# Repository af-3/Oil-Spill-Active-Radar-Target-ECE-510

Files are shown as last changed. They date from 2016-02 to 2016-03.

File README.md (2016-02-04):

# Oil-Spill-Active-Radar-Target-ECE-510
Cooperating radar target design for Portland State University ECE 510 winter 2016 Class<br>
[Radar Equations google Dock](https://docs.google.com/spreadsheets/d/1SBJ6qjm3yuyV2hIqerSS4fywFo_I5tQoiRfdYXWfvTU/pubhtml)

##Requirements
 * Must
   * Have a detection range of 10 meters
   * Be enviromentaly friendy specifically marine friendy
   * Build 8 working targets, but support at least 64 targets
   * Function correctly for at least 48 hours
   * Software must detect at least 64 targets
 * Should
   * Be no bigger then 3 X 3 X 2 inches
   * Have a detection range of 100 meters 
 * Could
   * Have smart tracking capability

##Additional Notes
 * Radar transmitter output power -6.02 dBm (.25 mW)
 * Radar operating frequincy is 2.304080 GHz
 * Antenna beam width on the vertical axis is about 68 digrees
 * Antenna beam width on the horizontal axis is about 52 digrees
 * Measured Receiver noise Floor is -120 dBm (10^-15 W)

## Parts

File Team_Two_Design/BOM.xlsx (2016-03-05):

Index | Quantity | Part Number | Description | Available Quantity | Unit Price USD | Extended Price USD | Price / 100 | Extended Price USD / 100
1 | 10 | BAT54S-FDICT-ND (http://www.diodes.com/_files/datasheets/ds11005.pdf) | DIODE ARRAY SCHOTTKY 30V SOT23-3 | 10 | $0.176 | $1.76 | $0.0958 | $9.58
2 | 10 | 296-12880-1-ND (http://www.ti.com/lit/ds/symlink/sn74auc1g14.pdf) | IC SINGLE INVERTER S-T SOT-23-5 | 10 | $0.365 | $3.65 | $0.2274 | $22.74
3 | 10 | 1276-1717-1-ND (http://www.samsungsem.com/kr/support/product-search/mlcc/__icsFiles/afieldfile/2015/06/03/CL05C681JB5NNNC.pdf) | CAP CER 680PF 50V NP0 0402 | 10 | $0.033 | $0.33 | $0.0153 | $1.53
4 | 10 | 497-6975-1-ND (http://www.st.com/web/en/resource/technical/document/datasheet/CD00173477.pdf) | IC REG LDO 0.8V | 10 | $0.800 | $8.00 | $0.2781 | $27.81
5 | 20 | 732-8541-1-ND (http://katalog.we-online.de/pbs/datasheet/865060640001.pdf) | CAP 1 UF 20% 50 V | 20 | $0.170 | $3.40 | $0.1231 | $12.31
6 | 10 | 712-1443-1-ND (http://www.johansontechnology.com/downloads/jti-cat-rf-ind.pdf) | IND 56 nH 5% 300 mA | 10 | $0.064 | $0.64 | $0.0445 | $4.45
7 | 10 | BAT-HLD-001-ND (https://www.digikey.com/product-detail/en/BAT-HLD-001/BAT-HLD-001-ND/1577235) | Battery Holder | 10 | $0.280 | $2.80 | $0.0436 | $4.36
8 | 10 | 541-220HCT-ND (https://www.digikey.com/product-detail/en/CRCW0603220RFKEA/541-220HCT-ND/1179731) | 220 ohm resistor | 10 | $0.081 | $0.81 | $0.0436 | $4.36
 |  |  |  |  | Total | $21.39 | Total / 100 | $78.42
 |  |  |  |  | Unit price / radar target | $2.14 | Unit Price / 100 targets | $0.78

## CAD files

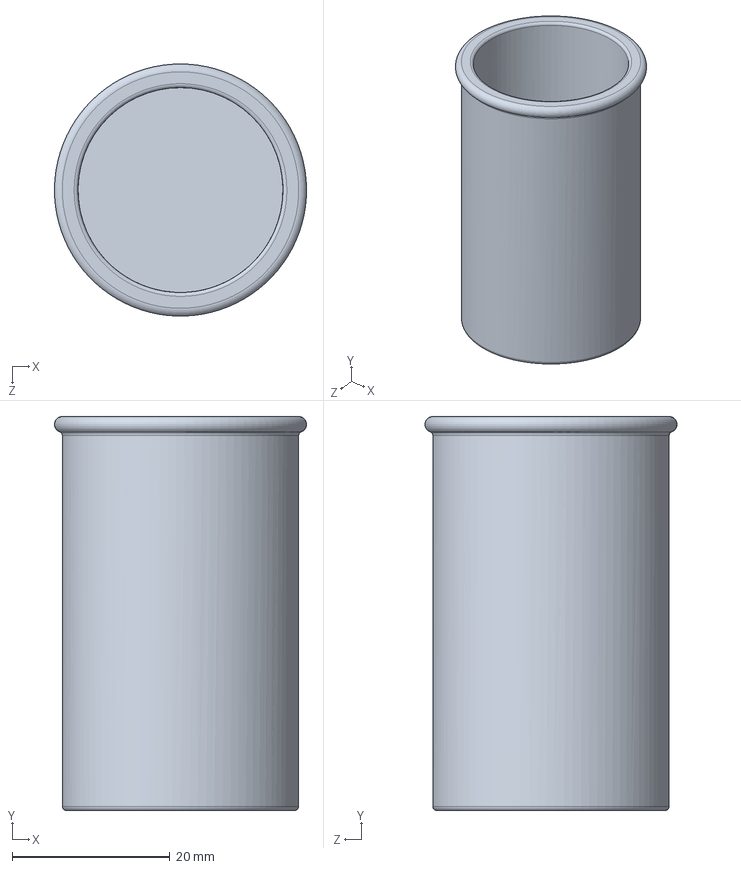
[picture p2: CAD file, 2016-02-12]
3D_CAD/Canister_No_Shelf.SLDPRT
32.0 x 50.0 x 32.0 mm

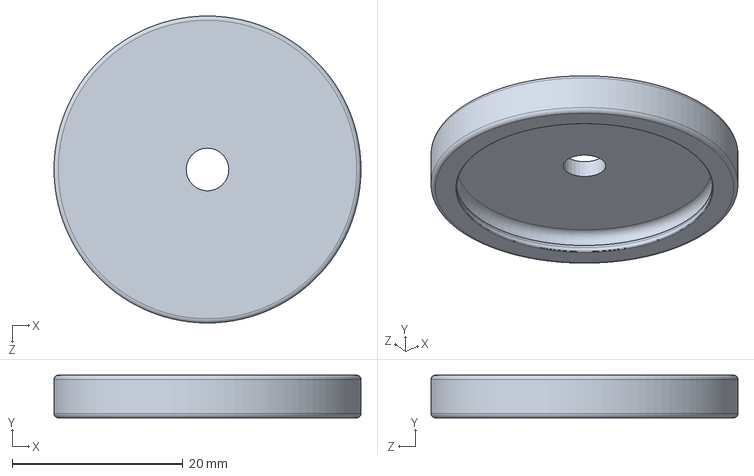
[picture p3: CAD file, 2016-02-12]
3D_CAD/Canister_Top.SLDPRT
36.0 x 5.00 x 36.0 mm

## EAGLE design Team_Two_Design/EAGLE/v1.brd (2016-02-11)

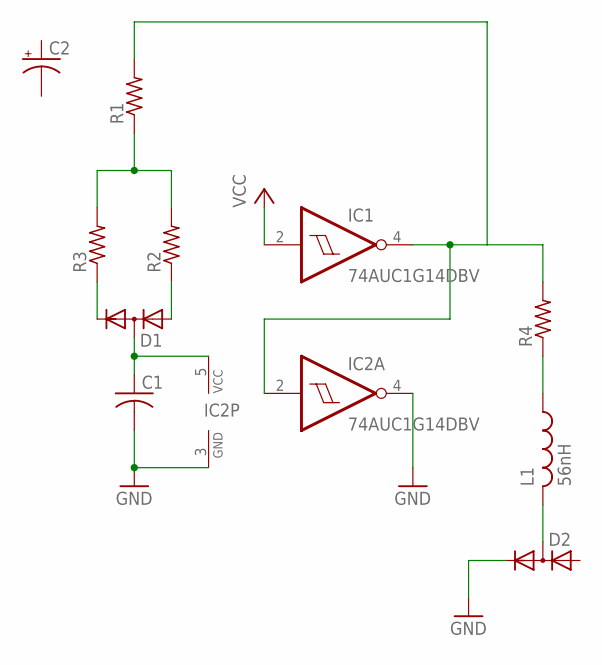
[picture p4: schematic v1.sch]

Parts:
C1: C-USC0402; C0402
C2: CPOL-USB; PANASONIC_B
D1, D2: DIODE_2CACA-SOT23; SOT23
IC1, IC2: 74AUC1G14DBV; SOT23-5
L1: 56nH; L2012C
R1, R2, R3, R4: R-US_R0805; R0805

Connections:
GND: C1.2, D2.2 (C), IC1.3 (GND), IC2.3, IC2.4 (O)
unnamed: D1.1 (A), R2.1
unnamed: D1.2 (C), R3.1
unnamed: IC1.4 (O), IC2.2 (I), R1.2, R4.2
unnamed: L1.1, R4.1
unnamed: R1.1, R2.2, R3.2
unnamed: C1.1, D1.3 (AC), IC2.5
unnamed: D2.3 (AC), L1.2
VCC: IC1.2 (I), IC1.5 (VCC)

Board: 2 copper layers, 11 parts (0 on the bottom side), 9 nets, no tracks yet.

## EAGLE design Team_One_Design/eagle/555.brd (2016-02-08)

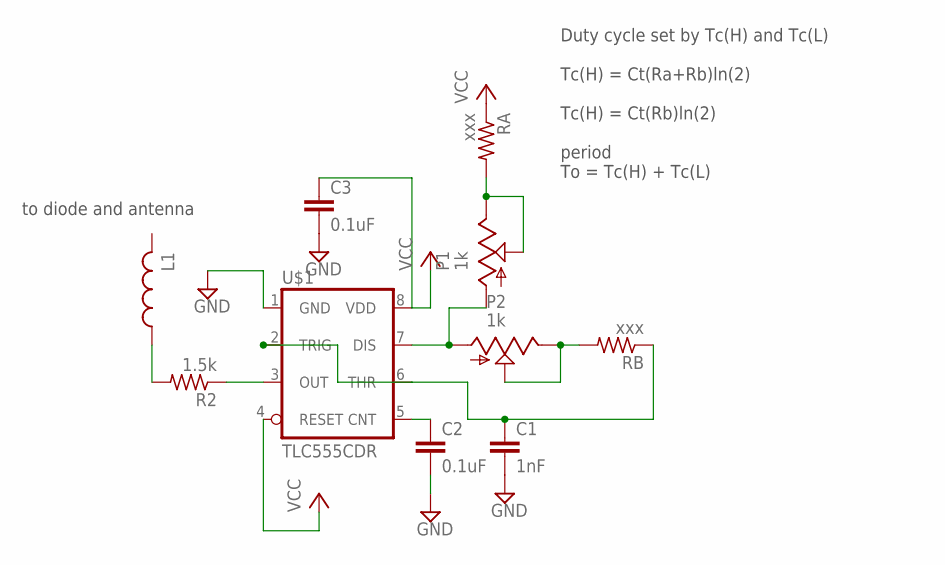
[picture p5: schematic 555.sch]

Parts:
C1: 1nF; C050-024X044
C2, C3: 0.1uF; C050-024X044
L1: L-USL2012C; L2012C
P1, P2: 1k; 3223J
R2: 1.5k; R0805
RA: xxx; R0805
RB: xxx; R0805
U$1: TLC555CDR; TLC555CRD

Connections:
GND: C1.2, C2.2, C3.2, U$1.1 (GND)
unnamed: P1.1 (A), P2.1 (A), U$1.7 (DIS)
unnamed: R2.1, U$1.3 (OUT)
unnamed: C1.1, RB.1, U$1.2 (TRIG), U$1.6 (THR)
unnamed: P2.2 (S), P2.3 (E), RB.2
unnamed: P1.3 (E), RA.2
unnamed: C2.1, U$1.5 (CNT)
unnamed: L1.1, R2.2
VCC: C3.1, RA.1, U$1.4 (RESET), U$1.8 (VDD)

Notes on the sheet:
to diode and antenna
Duty cycle set by Tc(H) and Tc(L) Tc(H) = Ct(Ra+Rb)ln(2) Tc(H) = Ct(Rb)ln(2) period To = Tc(H) + Tc(L)

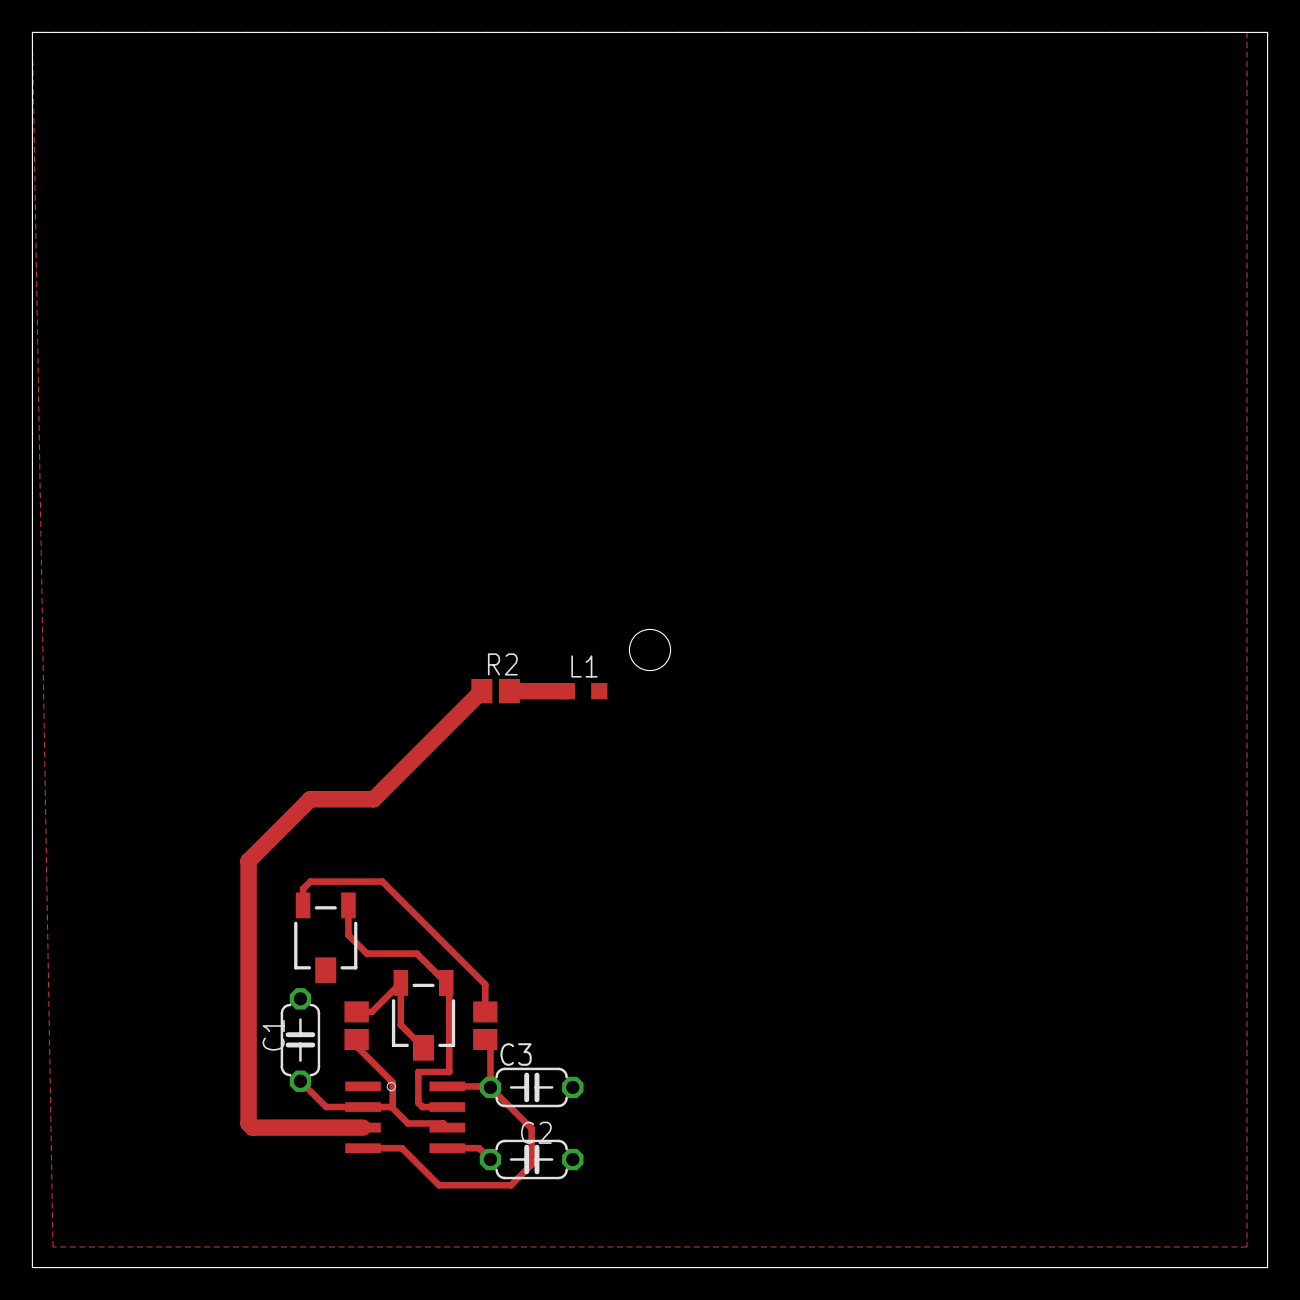
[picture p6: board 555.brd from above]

Board: 2 copper layers, 76.2 x 76.2 mm, 10 parts (0 on the bottom side), 9 nets.

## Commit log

2016-01-15 added an ltpisec simulation of the 555 timer. this circuit layout is set to 50 % duty cycle
2016-01-15 added footprint for 555 timer
2016-01-15 created the TLC555CDR timmer part including schematic, layout
2016-01-21 changed footprint of TLC555CDR
2016-01-21 added datasheets and 555 target eagle schematic and layout
    [555.brd, 555.sch]
2016-02-02 mofified 555 timer schematic and layout
    [555.brd, 555.sch]
2016-02-03 Team Two LTSpice design
    [555.brd, 555.sch]
2016-02-04 added datasheet for new RF diode, updated schem and layout for 555 circuit.
    [555.brd, 555.sch]
2016-02-09 Updated BOM
    added BOM with extended cost brake down
    [BOM.xlsx]
2016-02-10 Added thresholding of power
2016-02-11 Board and Schematic
    [v1.brd, v1.sch]
2016-02-12 Canister 1
    Film Canister
    [Canister_No_Shelf.SLDPRT, Canister_Top.SLDPRT]
2016-02-15 STL Files_Prototype 1
2016-02-16 KiCad files
    Added KiCad Project archive
    added board files
    [BOM.xlsx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]
2016-02-18 updated schematic and layout of 555 timer board
    [555.brd, 555.sch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]
2016-02-18 BOM
    Updated BOM
    [BOM.xlsx]
2016-02-18 BRD update
    Increased isolation electrolytic on capacitors
    Changed Battery Footprint
    [Target-B.Cu.gbr, Target-B.SilkS.gbr, Target-Edge.Cuts.gbr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]
2016-02-29 added dimmesnsions to target layout
    [555.sch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]
